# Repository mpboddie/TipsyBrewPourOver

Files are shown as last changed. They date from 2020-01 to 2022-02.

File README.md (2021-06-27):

# TipsyBrew Pour Over Robot (POR for short)
This is an exploratory/educational project that will attempt to tackle a few basic tasks of brewing a damn good cup of coffee.

So the design and approach of this project is to emphasize simplicity and approachability. The basic problems being solved here could be done many ways, but I am going to approach it with these priciples:
1. Use basic consumer items and realtively easy to obtain electrical components. I want to use very common hobbiest level components so that you can easily use what you may have or what you can easily and cheaply obtain where possible. I also want the design to be easily adapted so if you are not able to get the same exact item or you can get a similar one for half the cost then you should do so without major project changes.
2. Make it educational. I am hoping people follow along with this project as it unfolds. I will try to break it down to basic concepts so that you can either learn, skim, or critique.
3. Take what you want from it. I'm not going to have this project completed tomorrow and my decisions may not suit all your needs. But if I move too slow for you and you are capable enough, jump right ahead of my progress. If you are looking to say heat your water with some volcanic geothermal situation going on near you, dump my water heating solution.
4. Cover the basics first. If you make a feature request for a something like a touchscreen or wifi before I can make a solid cup of coffee, expect me to ignore it until later. I believe in simplicity first. However, this is an open project so if you want to add that in a branch, go for it.
5. Communication. I will do my best to convey the reasons behind my decisions as I go. I am sure I will make some mistakes, so please do your best to reciprocate in a constructive manner.

Keep tabs on the everyday progress of this project at [TipsyBrew](https://tipsybrew.com/tags/pourover/). Project code and models will be stored here on GitHub though.

## EarlyPhase (depricated)
This is the exact code that the Phase 0.5 demonstration used. There are some slight issues with this, but nothing that prevents a cup of coffee from being made. I would have preferred to hold it back for some polishing before putting it up here, but I am trying to fight those instincts and make this as public as possible. As always, check [TipsyBrew](https://tipsybrew.com/blog/2020-03-01-success-first-cup-video/) for the 0.5 demonstration and related news on the [pour over project](https://tipsybrew.com/projects). Early Phase was kind of like the moon shot code to demonstrate that the POR would work. It is still being used to make coffee daily to fuel Tipsy during mkII progress, but it is not long for this world.

## Mk II has begun
Mark II of the POR is aimed towards a complete kit for others to build. That means I am trying to create a stable design. At the moment of writing it will be the leading edge design, but once completed I will do my best to heavily document it and hopefully a community will grow with it.

MkII will be TipsyBrew POR's first release.

MkII as of this writing is not complete. However, you are more than welcome to give the code a spin. You will need an ESP32 and an SPI LCD touchscreen using the ILI9341 driver. I believe most of the screens of that type are 320x240 and things will probably work best if you stick with that. The screen I am using at the moment is 2.8 inches, but that has no bearing on get the code running.

Current schematic is below (keep in mind I'm focused on the software at the moment and have already used the missing assorted hardware on MkI):
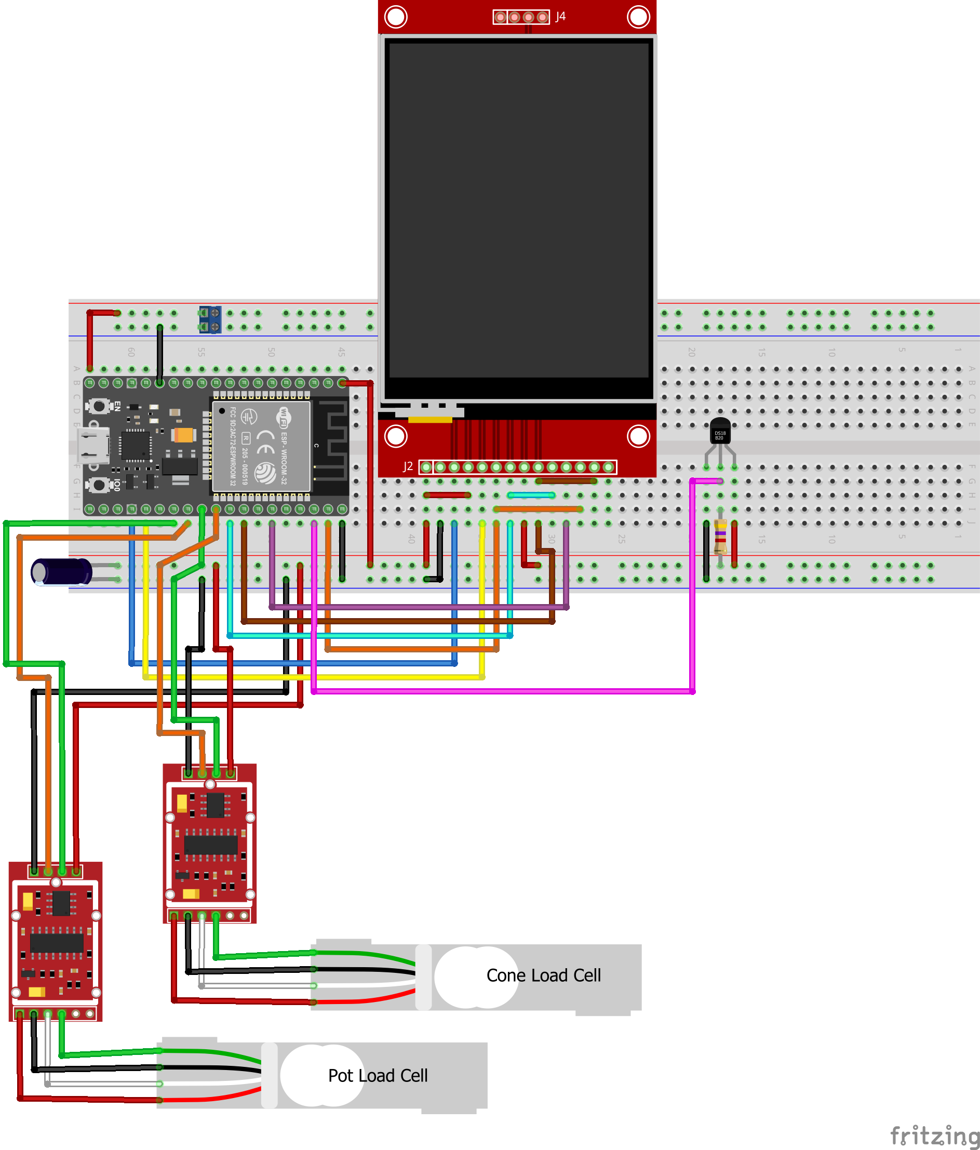
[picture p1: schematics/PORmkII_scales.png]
Schematic

The 10μF capacitor that is bridging GND and 3.3v may not be necessary, but for some ESP32 boards it will prevent the brownout error. The resistor on the DS18B20 is 4.7k Ω.

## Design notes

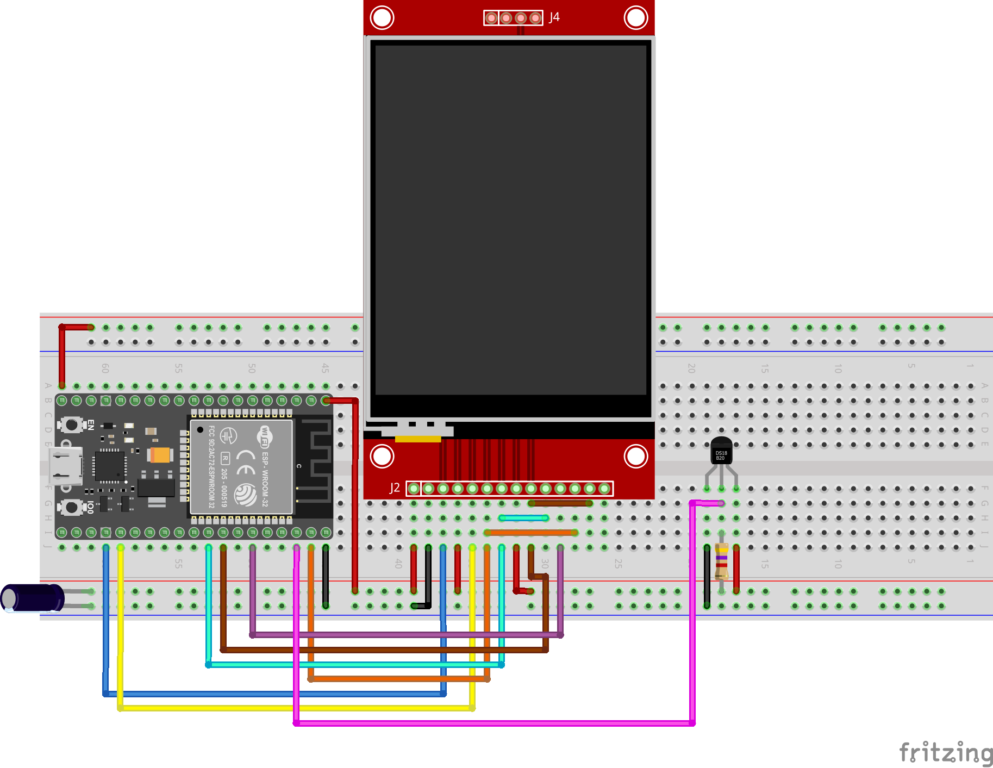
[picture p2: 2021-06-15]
schematics/PORmkII.png

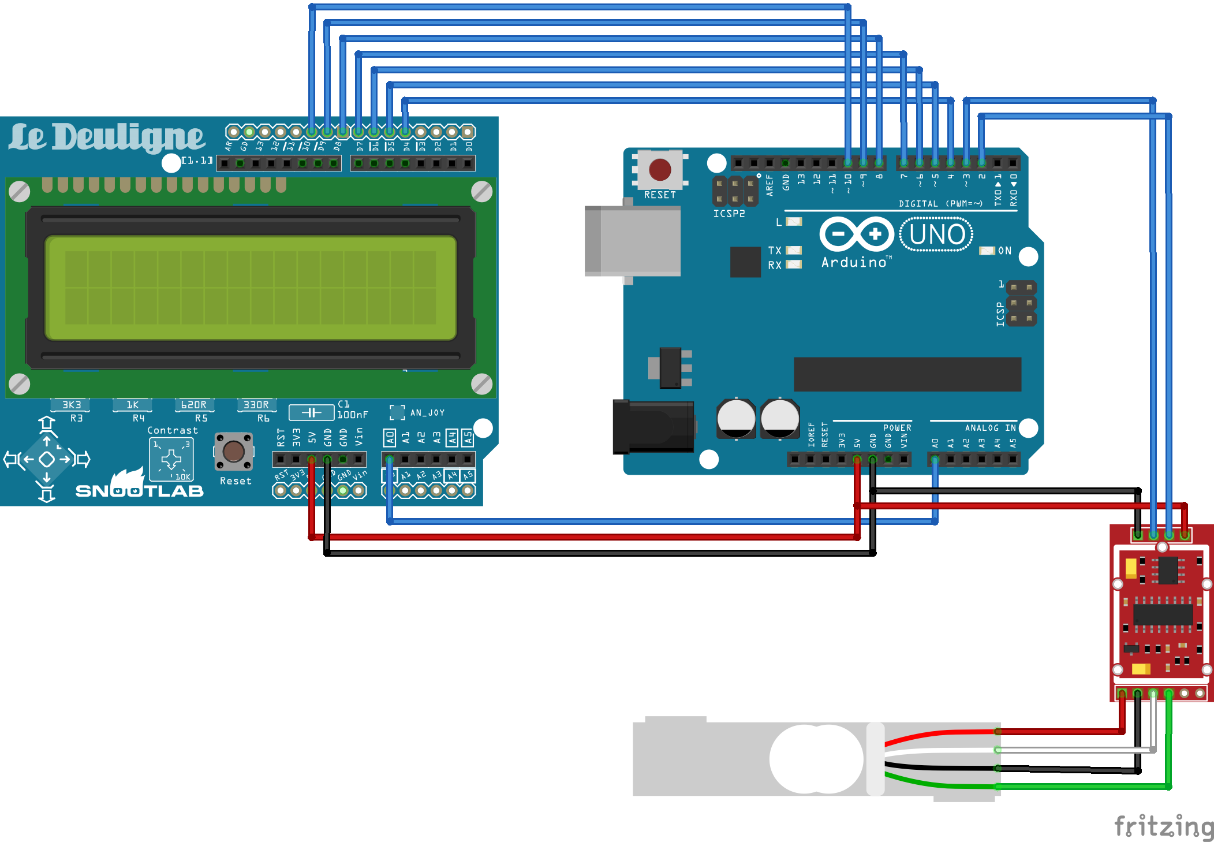
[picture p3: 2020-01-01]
examples/Weight/LoadCell_bb.png

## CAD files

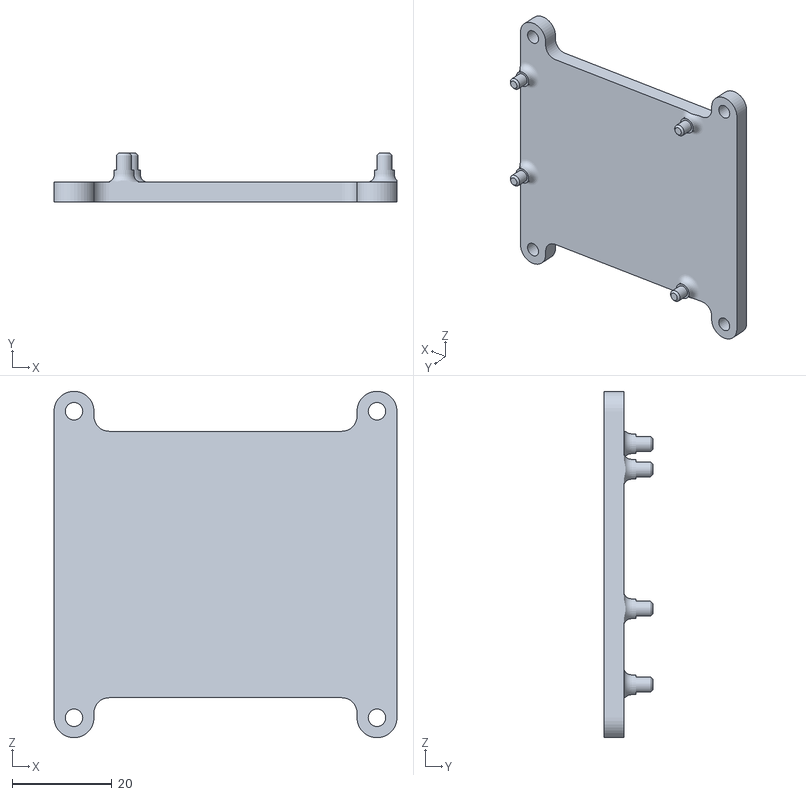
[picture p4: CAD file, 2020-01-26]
3dPrints/ArduinoMount.stl
68.6 x 9.90 x 69.3

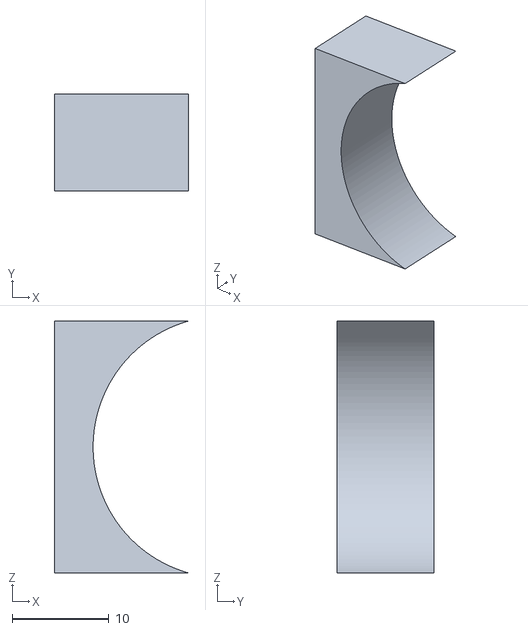
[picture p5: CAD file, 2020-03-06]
3dPrints/DiaphragmPumpMount/DpumpBigBottom.stl
13.9 x 10.0 x 26.0

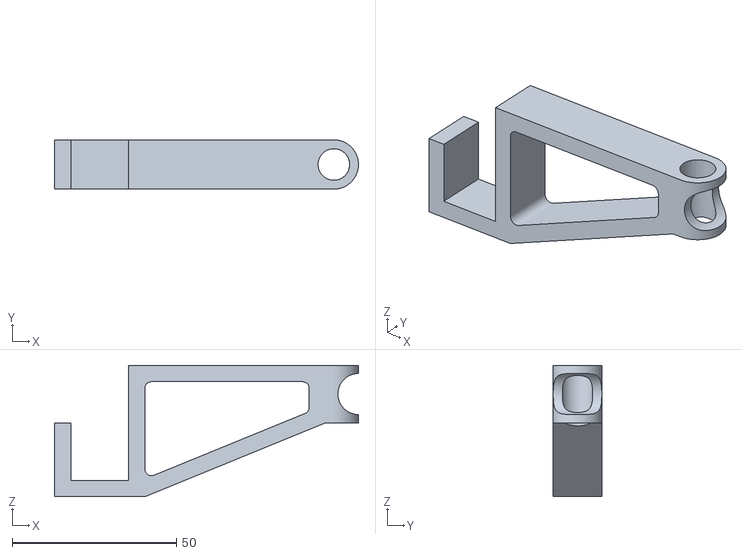
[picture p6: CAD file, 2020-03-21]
3dPrints/Spoon/HoseHolder.stl
92.5 x 15.0 x 40.0

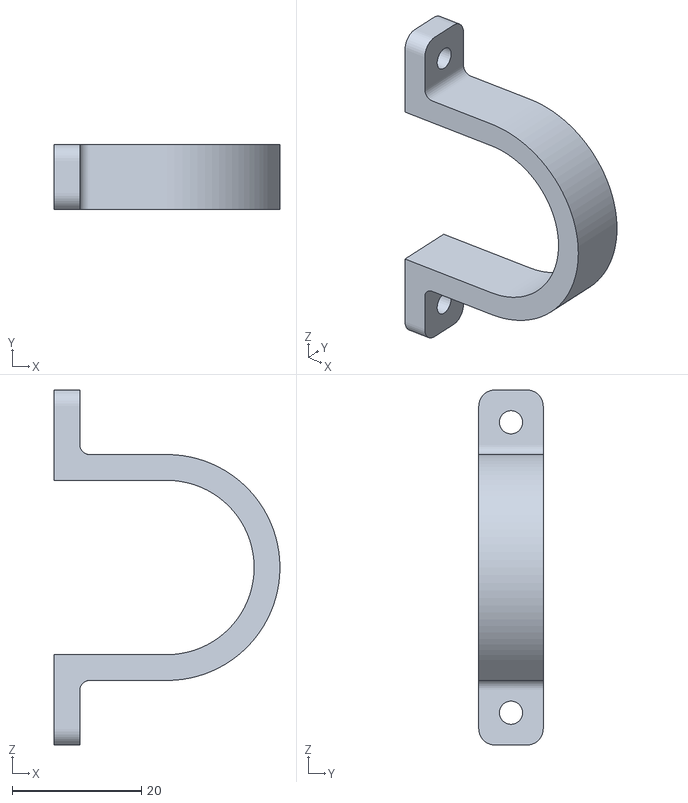
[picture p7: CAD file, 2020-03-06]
3dPrints/DiaphragmPumpMount/DpumpBigTop.stl
35.0 x 10.0 x 55.0

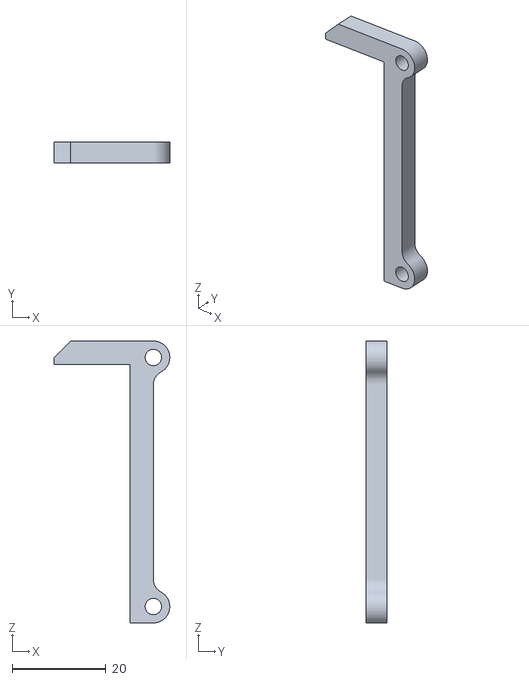
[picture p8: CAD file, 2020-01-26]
3dPrints/digitalPlatformHolder.stl
24.6 x 4.50 x 60.0

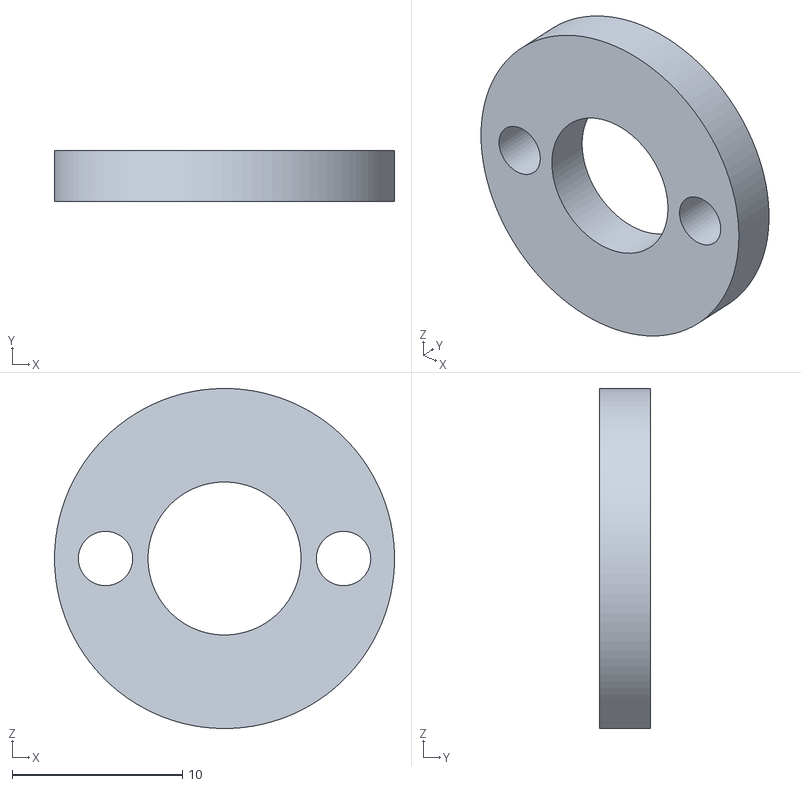
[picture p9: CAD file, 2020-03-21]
3dPrints/Spoon/Spoon2ServoTop.stl
20.0 x 3.00 x 20.0

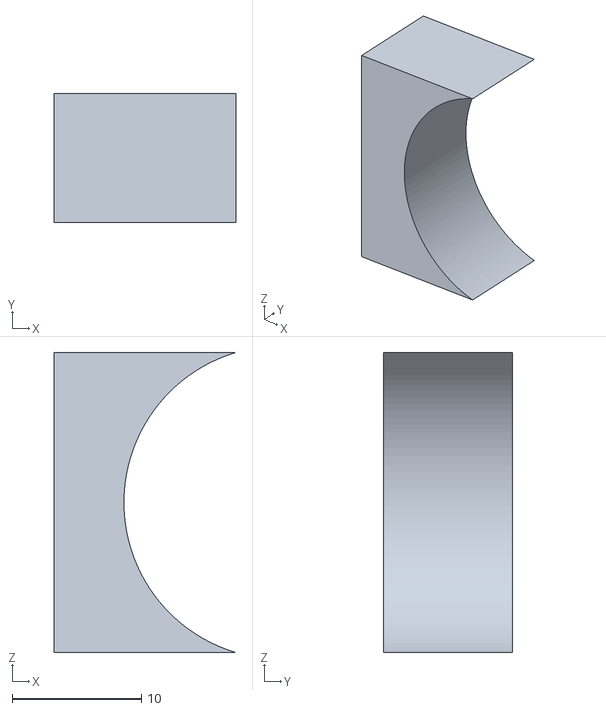
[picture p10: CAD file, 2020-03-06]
3dPrints/DiaphragmPumpMount/DpumpLittleBottom.stl
14.1 x 10.0 x 23.2

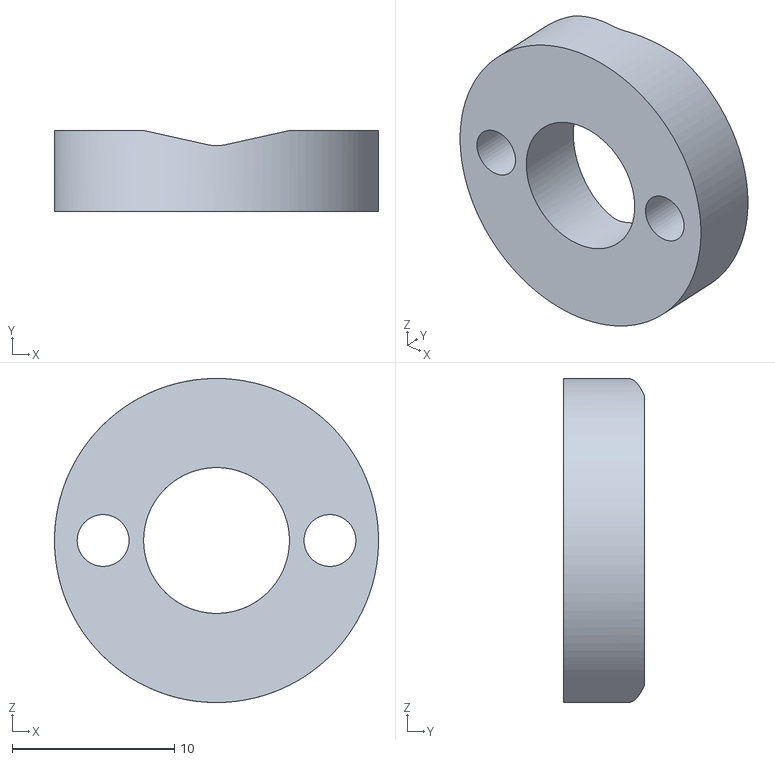
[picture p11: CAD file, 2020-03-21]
3dPrints/Spoon/Spoon2ServoBottom.stl
20.0 x 5.00 x 20.0

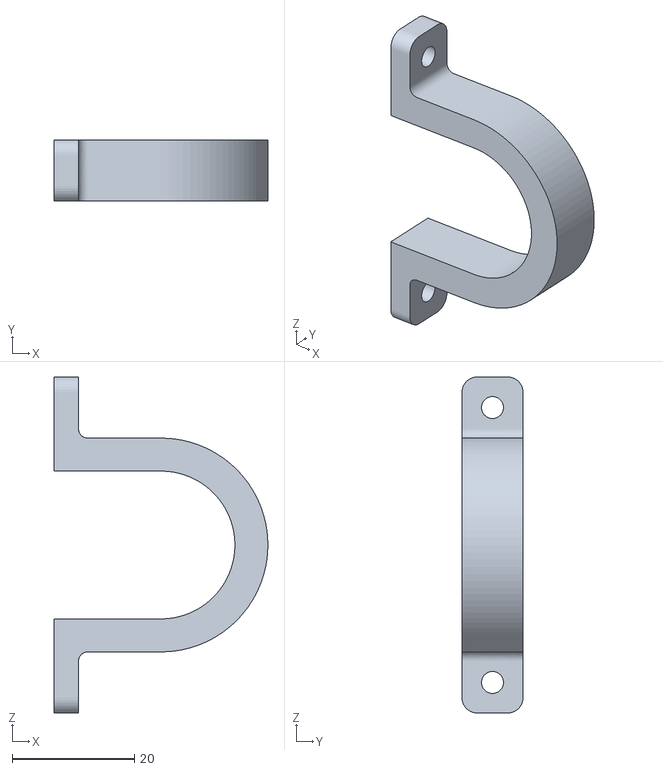
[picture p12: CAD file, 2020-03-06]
3dPrints/DiaphragmPumpMount/DpumpLittleTop.stl
35.0 x 10.0 x 55.0

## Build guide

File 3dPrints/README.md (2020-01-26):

3D Print Files
==============
Here you will find any STL files that were used to make the TipsyBrew pour over machine.

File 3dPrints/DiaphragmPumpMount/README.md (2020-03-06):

### Diaphragm Pump Mount
This mount is pretty basic and not the most elegant but works great. It is for a 12V diaphragm pump that was supplied to me by a generous TipsyBrew Discord user. The pump head is slightly larger than the motor, so there are two separate brackets. Each bracket has a top that goes around the pump and a bottom that gets sandwiched between the pump and the surface you are attaching it to. Although I have not tried it, I suppose you could just use one or two brackets on just the motor or just the head part. The screw holes were made for a #6 screw (sorry metric people, it is what I had laying around).

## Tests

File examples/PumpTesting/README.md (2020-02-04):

Pump Testing
============
**Work in Progress** - Expect some action over here

I have written some code, it is a bit messy and COMPLETELY UNTESTED at the moment.

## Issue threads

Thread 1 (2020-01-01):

Compare HX711 libraries

mpboddie, 2020-01-01:
https://github.com/bogde/HX711 is currently used in the weight example. It may be worthwhile to investigate https://github.com/olkal/HX711_ADC though. It looks like it has a built-in smoothing option. It could be useful.

mpboddie, 2021-06-14:
I've used the bogde library for a while now and I really don't see a need to complicate things. Unless other users see an issue with weight later on, I'm not going to work it.

Closed 2021-06-14.

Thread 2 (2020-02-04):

Evaluate pumps

mpboddie, 2020-02-04:
I've got a commercial diaphragm pump and a self designed peristaltic pump at my disposal at the moment. I need to evaluate what I have to determine the best pump for phase 1. It may also be that the phase 1 pump is not the best pump for the long haul, but lets take it one step at a time.

mpboddie, 2020-03-06:
The diaphragm pump kicked ass for phase 0.5. The peristalitic pump needs some revisions, but I still think it could be a good backup for 3D printing junkies or people who can not obtain a diaphragm pump easily.

mpboddie, 2021-06-14:
The diaphragm pump ended up being not food safe for the parameters used. I have purchased a couple off the shelf peristaltic pumps that seem to be good. They both have the same peristaltic pump head but one is a DC motor and the other a stepper.

A decision has not been made on which one to use yet, so this is still open.

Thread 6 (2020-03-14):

Library organization

mpboddie, 2020-03-14:
Is there a way to link libraries in Arduino? Are we putting enough info in the code about the libraries used?

mpboddie, 2021-06-14:
The move to PlatformIO has fixed this.

Closed 2021-06-14.

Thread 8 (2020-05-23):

Filter rinse does not tare after completion

mpboddie, 2020-05-23:
If the user goes to the filter rinse state, upon completion it goes to the weigh grounds state but it doesn't tare the scale when doing so. The workaround is just having the user manually tare, but it would be better if it was automatically done.

mpboddie, 2021-06-14:
This is an earlyPhase branch issue and we have moved on to MkII. This will not be fixed.

Closed 2021-06-14.

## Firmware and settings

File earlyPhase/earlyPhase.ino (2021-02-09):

// TipsyBrew Pour Over Machine
// by Tipsy
// See http://tipsybrew.com for complete project details
// Version 0.5
// This is a rough start connecting the following components in unison
// - Load cell with HX711 amplifier
// - Diaphragm pump (12v) with L298N driver
// - SSD1306 OLED display (128x64)
// - Keypad 2x3
// Initially this is going to have a limited feature set. You may find it pretty
// rigid and mostly hard coded, however I've had a lot of odd fluke like setbacks
// so I just want to get this thing making a cup of coffee.

#include <SPI.h>
#include <Wire.h>
#include <Adafruit_GFX.h>
#include <Adafruit_SSD1306.h>
#include <Keypad.h>
#include "HX711.h"
#include "ServoEasing.h"
#include "triggy.h"
#include "earlyLibs.h"
#include "screens.h"

// ### App settings ###
// Variables that are required or encouraged to be customized will go here

const byte coffeeRatio = 16;  // Coffee to water ratio (lower number = stronger coffee)
const float waterLoss = 1.995;  // This is used to calculate the amount of water is retained by the coffee grounds

// Calibration factor dependent on your load cell
// You absolutely need to tweak this for your hardware
// See https://tipsybrew.com/blog/2020-01-01-the-hookup-weight-sensor/ for more info
// If you have problems with this let me know so I can make a better calibration guide
#define calibration_factor 1695.0

// Pump speeds
// These define the speed of the pump during bloom and brew, higher = faster
#define BLOOM_SPEED 100
#define BREW_SPEED 90
#define BLOOM_WAIT 30000
#define DRAWDOWN_TIME 20000

// Pour arm settings
// These values should be changed to fit your brewer. If you have a limited space there is nothing preventing the servo from turning into your stand, so maybe test gently.

// left to right is referred to as the X
//const int leftAngle = 88;   // servo setting to set arm to the human's far left perspective
//const int rightAngle = 124; // servo setting to set arm to the human's far right perspective
#define MID_ANGLE 94  // This should be 90 on a 180 degree servo... but sometimes shit happens and the worlds don't align

// front to back is referred to as the Y
const int frontDistance = 5; // servo setting to set arm to the human's far front perspective
const int backDistance = 180; // servo setting to set arm to the human's far back perspective

// number of ms between steps of arm move
// NOTE: this is kind of done in a dumb way, but it is an example of GEFN (good enough for now)
#define ARM_SPEED 100

// Do change the pourCoord arrays if you want
#define NUM_BLOOM_SPOTS 10
pourCoord bloomSpots[NUM_BLOOM_SPOTS];

// BREW_RADIUS and BREW_DISTANCE are in servo steps as units
// Radius defines the max radius of the brew circle
// Distance is the servo arm distance to the center of the brewer, assuming the arm is also angle center
#define BREW_RADIUS 60
#define BREW_DISTANCE 102.5
#define BREW_RESOLUTION 20  // must divide 360 evenly
pourCoord brewSpots[BREW_RESOLUTION];

// Kettle values
#define KETTLE_ON 74
#define KETTLE_NEUTRAL 50
#define KETTLE_OFF 32

// Turns on a servo test during the startup screen
const bool servoTest = false;
// debug flag
const bool debug = false;

// Cone limit
// I STRONGLY SUGGEST you start small and work your way up if you so choose on cone limit.
// This limits the number of ml dispensed during a brew cycle before pausing for a drawdown.
// Let me say it another way, if you increase this too much HOT WATER WILL OVERFLOW making a huge mess in the best case scenario.
const int coneLimit = 225;

// ### Functions and variable initialization ###

enum AppModeValues
{
  APP_INTRO_SCREEN,
  APP_NORMAL_MODE,
  APP_SERVO_TEST,
  APP_FILTER_RINSE,
  APP_CONFIRM_START,
  APP_BLOOM,
  APP_BREW,
  APP_BREW_COMPLETE
};

byte appMode = APP_INTRO_SCREEN;

void runPump();
void stopPump();
void pumpSpeed(byte dcSpeed);

// Timing variables
unsigned long startMillis;
unsigned long currentMillis;

// Weight variables
float weightRead = 0;
float prevWeight = 0;
float groundWeight = 0;

// Bloom time
unsigned long bloomTimer;

// Brew variables
int brewPosition = 0;
int currentAngle;
int currentDistance;

void setup() {
  Serial.begin(9600);

  // initialize with the I2C addr 0x3C
  if(!display.begin(SSD1306_SWITCHCAPVCC, 0x3C)) {
    Serial.println(F("SSD1306 allocation failed"));
    for(;;); // Don't proceed, loop forever
  }

  // Set all the motor control pins to outputs
  pinMode(enA, OUTPUT);
  pinMode(in1, OUTPUT);
  pinMode(in2, OUTPUT);

  // Turn off motors - Initial state
  stopPump();
  
  // Title screen... completely unecessary
  display.clearDisplay();
  // Display bitmap
  display.drawBitmap(0, 0, TipsyBrew, 128, 64, WHITE);
  display.display();
  startMillis = millis();
  while( millis() - startMillis < 5000 ) {
    if ( keypad.getKey() ) break;
  }

  // populate brew path
  float angleIncrement = 360/BREW_RESOLUTION;
  for (int i=0; i<BREW_RESOLUTION; i++) {
    Serial.print(i);
    double distance = SASdistance(BREW_DISTANCE, BREW_RADIUS, i*angleIncrement);
    double angle = SSAngle(BREW_RADIUS, i*angleIncrement, distance) + MID_ANGLE;
    //distance = reverseDistance(distance);
    brewSpots[i] = {(int)angle, (int)distance};
    
    Serial.print(F(" - ("));
    Serial.print(angle, 1);
    Serial.print(F(", "));
    Serial.print(distance, 1);
    Serial.println(F(")"));
    if (debug) {
      display.clearDisplay();
      display.setTextSize(1);
      display.setTextColor(WHITE);
      display.setCursor(0,10);
      display.println(i);
      display.print(angle, 1);
      display.print(F(", "));  
      display.println(distance, 1);
      display.display();
      delay(500);
    }
  }

  int bloomRadius = 30;
  angleIncrement = 360/NUM_BLOOM_SPOTS;
  for (int i=0; i<NUM_BLOOM_SPOTS; i++) {
    double distance = SASdistance(BREW_DISTANCE, bloomRadius, i*angleIncrement);
    double angle = SSAngle(bloomRadius, i*angleIncrement, distance) + MID_ANGLE;
    distance = reverseDistance(distance);
    bloomSpots[i] = {(int)angle, (int)distance};
  }
  
  if ( servoTest ) {
    Serial.println(F("Servo Test"));
    // servo test cycle
    angleIncrement = 360/BREW_RESOLUTION;
    angleServo.attach(anglePin, 1300, 1700);
    distanceServo.attach(distancePin);
    angleServo.setSpeed(10);
    distanceServo.setSpeed(70);
    distanceServo.write(93);
    angleServo.write(93);
    delay(3000);
    for (int i=0; i < BREW_RESOLUTION; i++) {
      Serial.print(i*angleIncrement);
      Serial.print(F(" - ("));
      Serial.print(brewSpots[i].angle, 1);
      Serial.print(F(", "));
      Serial.print(brewSpots[i].distance, 1);
      Serial.println(F(")"));
      distanceServo.startEaseTo(brewSpots[i].distance);
      angleServo.startEaseTo(brewSpots[i].angle);
      synchronizeAllServosAndStartInterrupt();
      while(distanceServo.isMoving() || angleServo.isMoving()) {
        if ( distanceServo.isMoving() ) {
          Serial.print(F("Distance "));
        }
        if ( angleServo.isMoving() ) {
          Serial.print(F("Angle"));
        }
        Serial.println(F(" "));
      }
    }
    distanceServo.startEaseTo(brewSpots[0].distance);
    angleServo.startEaseTo(brewSpots[0].angle);
    synchronizeAllServosAndStartInterrupt();
    while(distanceServo.isMoving() || angleServo.isMoving()) {
      if ( distanceServo.isMoving() ) {
        Serial.print(F("Distance "));
      }
      if ( angleServo.isMoving() ) {
        Serial.print(F("Angle"));
      }
      Serial.println(F(" "));
    }
    angleServo.detach();
    distanceServo.detach();
    Serial.print(F("Done with Servo Test"));
  }

  startKettle();
  
  // Make sure the pour spout is out of the way for convenient dead bean loading
  angleServo.attach(anglePin, 1000, 2000);
  distanceServo.attach(distancePin);
  angleServo.write(MID_ANGLE);
  distanceServo.write(frontDistance);
  delay(500);
  distanceServo.detach();
  angleServo.detach();
  
  // Intro
  display.clearDisplay();
  display.setTextSize(1);
  display.setTextColor(WHITE);
  display.setCursor(0,10);
  display.println(F("Place a prepared"));
  display.println(F("brewer in the machine"));  
  display.println(F("WITHOUT any grounds"));
  display.display();
  delay(1000);
  display.setCursor(10,44);
  display.println(F("Press any key to"));
  display.println(F("continue."));
  display.display();

  scale.begin(LOADCELL_DOUT_PIN, LOADCELL_SCK_PIN);
  scale.set_scale(calibration_factor);
  //Assuming there is no weight on the scale at start up, reset the scale to 0
  scale.tare();
}

void loop() {
  
  char key = keypad.getKey(); // Read the key

  switch (appMode)
  {
    case APP_INTRO_SCREEN :
      if (key) {
        if (key == 'U') {
          display.clearDisplay();
          appMode = APP_FILTER_RINSE;
        } else if (key == 'L') {
          display.clearDisplay();
          currentAngle = 90;
          currentDistance = 90;
          angleServo.attach(anglePin, 1000, 2000);
          distanceServo.attach(distancePin);
          angleServo.write(currentAngle);
          distanceServo.write(currentDistance);
          delay(100);
          angleServo.detach();
          distanceServo.detach();
          appMode = APP_SERVO_TEST;
        } else {
          scale.tare();
          display.clearDisplay();
          appMode = APP_NORMAL_MODE;
          weightRead = -100; // this forces a refresh
        }
      }
      break;
    case APP_SERVO_TEST :
      displayServoTest(currentAngle, currentDistance);
      if (key == 'U') {
        if (currentDistance < 180) {
          currentDistance++;
          distanceServo.attach(distancePin);
          distanceServo.write(currentDistance);
          delay(100);
          distanceServo.detach();
        }
      } else if (key == 'D') {
        if (currentDistance > 0) {
          currentDistance--;
          distanceServo.attach(distancePin);
          distanceServo.write(currentDistance);
          delay(100);
          distanceServo.detach();
        }
      } else if (key == 'L') {
        if (currentAngle > 0) {
          currentAngle--;
          angleServo.attach(anglePin, 1000, 2000);
          angleServo.write(currentAngle);
          delay(100);
          angleServo.detach();
        }
      } else if (key == 'R') {
        if (currentAngle < 180) {
          currentAngle++;
          angleServo.attach(anglePin, 1000, 2000);
          angleServo.write(currentAngle);
          delay(100);
          angleServo.detach();
        }
      } else if (key) {
        display.clearDisplay();
        appMode = APP_INTRO_SCREEN;
        displayIntro();
      }
      break;
    case APP_FILTER_RINSE :
      displayFilterRinse();
      if (key == 'L') {
        display.clearDisplay();
        appMode = APP_NORMAL_MODE;
      } else if (key == 'D') {
        display.clearDisplay();
        display.setTextSize(2);
        display.setTextColor(WHITE);
        display.setCursor(0,10);
        display.println(F("  Rinsing"));
        display.println(F("    In"));
        display.println(F(" Progress"));
        display.display();
        int filterResolution = 36;
        pourCoord filterRinse[filterResolution];
        drawCircle(50, filterResolution, BREW_DISTANCE, MID_ANGLE, filterRinse);
        angleServo.attach(anglePin, 1000, 2000);
        distanceServo.attach(distancePin);
        pumpSpeed(BREW_SPEED);
        runPump();
        for(int i = 0; i < filterResolution; i++) {
          angleServo.write(filterRinse[i].angle);
          distanceServo.write(filterRinse[i].distance);
          delay(200);
        }
        angleServo.write(filterRinse[0].angle);
        distanceServo.write(filterRinse[0].distance);
        delay(100);
        stopPump();
        angleServo.detach();
        distanceServo.detach();
      }
      break;
    case APP_NORMAL_MODE :
      // Display active weight, calculate what the weight means for finished coffee
      prevWeight = weightRead;
      weightRead = scale.get_units();
      if ( weightRead < 1 ) {
        display.clearDisplay();
        display.setTextSize(2);
        display.setTextColor(WHITE);
        display.setCursor(0,20);
        display.println(F(" FEED ME"));
        display.println(F("DEAD BEANS"));
        display.display();
      } else if ( weightRead < 5 ) {
        display.clearDisplay();
        display.setTextSize(2);
        display.setTextColor(WHITE);
        display.setCursor(0,10);
        display.println(F("MORE BEANS"));
        display.println(F(" STOOPID"));
        display.println(F("HOOMAN!!!"));
        display.display();
      } else if ( abs(weightRead - prevWeight) > 0.1 ) { // refresh display
        display.clearDisplay();
        display.setTextSize(1);
        display.setTextColor(WHITE);
        display.setCursor(0,10);
        display.print(F("Dead beans: "));
        display.print(weightRead, 1);
        display.println(F(" g"));
        display.print(F("Water used: "));
        display.print((weightRead*coffeeRatio), 1);
        display.println(F(" ml"));
        display.print(F("Coffee made:"));
        display.print(((weightRead*coffeeRatio) - (weightRead*waterLoss)), 1);
        display.println(F(" ml")); 
        display.println(F(" "));
        display.println(F("Press UP to tare"));
        display.println(F("COFFEE NOW to Brew"));
        display.display();  
      }
      if ( key == 'U' ) {
        // Tare the scale with the A button
        scale.tare();
      } else if ( key == 'C' ) {
        // Start the brew with the * button
        appMode = APP_CONFIRM_START;
        display.clearDisplay();
        display.setTextSize(1);
        display.setTextColor(WHITE);
        display.setCursor(0,0);
        display.println(F("You are about to make"));
        display.print(((weightRead*coffeeRatio) - (weightRead*waterLoss)), 1);
        display.println(F(" ml of coffee"));
        display.println(F(" "));
        display.println(F("Are you sure?"));
        display.println(F(" "));
        display.println(F("SELECT to Continue"));
        display.println(F("ANY KEY to Cancel"));
        display.display();
      }
      break;
    case APP_CONFIRM_START :
      // Confirm start with the 1 button
      if ( key == 'S' ) {
        groundWeight = weightRead;
        appMode = APP_BLOOM;
        display.clearDisplay();
      } else if ( key ) {
        appMode = APP_NORMAL_MODE;
        display.clearDisplay();
        weightRead = -100; // forces a refresh
      }
      break;
    case APP_BLOOM :
      // Dispense total water*bloom and wait
      display.setTextSize(1);
      display.setTextColor(WHITE);
      display.setCursor(0,0);
      display.println(F("Bloom in Progress!"));
      display.println(F("Do not touch brewer"));
      display.display();
      scale.tare(); // weight from this point on is water dispensed only

      // To start the bloom put the spout dead center
      angleServo.attach(anglePin, 1000, 2000);
      distanceServo.attach(distancePin);
      angleServo.write(MID_ANGLE);
      distanceServo.write(BREW_DISTANCE);
      delay(500);
      distanceServo.detach();
      angleServo.detach();
      
      pumpSpeed(BLOOM_SPEED);
      runPump();
      bloomTimer = millis();
      while (scale.get_units() < groundWeight) {
        // possibly display weight to the user, but do they really care?
        // just do nothing for now
      }
      bloomTimer = millis() - bloomTimer; // tells us how long the first half of the bloom took
      stopPump();

      brewPosition = 0;
      bloomTimer = 0;
      angleServo.attach(anglePin, 1000, 2000);
      distanceServo.attach(distancePin);
      runPump();
      while (scale.get_units() < (2*groundWeight)) {
        if ( millis() >= bloomTimer + ARM_SPEED ) {
          bloomTimer = millis();
          angleServo.write(bloomSpots[brewPosition % NUM_BLOOM_SPOTS].angle);
          distanceServo.write(bloomSpots[brewPosition % NUM_BLOOM_SPOTS].distance);
          brewPosition += 1;
        }
      }
      stopPump();
      distanceServo.detach();
      angleServo.detach();
      
      display.clearDisplay();
      display.setTextSize(1);
      display.setTextColor(WHITE);
      display.setCursor(0,20);
      display.println(F("     BLOOMING"));
      display.println(F("Do not touch brewer"));
      display.print(scale.get_units(), 1);
      display.println(F(" g dispensed"));
      display.display();
      delay(BLOOM_WAIT);

      // Adjust spout to center
      angleServo.attach(anglePin, 1000, 2000);
      distanceServo.attach(distancePin);
      currentAngle = (int) MID_ANGLE;
      currentDistance = (int) BREW_DISTANCE;
      angleServo.write(currentAngle);
      distanceServo.write(currentDistance);
      delay(100);
      distanceServo.detach();
      angleServo.detach();
      
      // Move on to the brewing step
      appMode = APP_BREW;
      break;
    case APP_BREW :
      pumpSpeed(BREW_SPEED);
      bool complete = false;
      float waterRound = scale.get_units();   // This acts as a sort of tare without losing live total weight, subtract it from the current weight to get the weight of the current pour
      
      // For loop dispense <coneLimit> ml of water or amount remaining then wait
      while (scale.get_units() < (coffeeRatio * groundWeight)) { // stay in loop until we have pumped the needed water
        float waterLeft = (coffeeRatio * groundWeight) - scale.get_units();   // live count of water still required
        if ( waterLeft > coneLimit ) {
          waterLeft = coneLimit;    // if the amount of water required is over the amount of water you want in the cone at one moment just pour the max amount
        } else {
          complete = true;          // else pour what is left and call it
        }
        
        startMillis = millis();
        brewPosition = 0;
        unsigned long lastMove = startMillis;
        
        angleServo.attach(anglePin, 1000, 2000);
        distanceServo.attach(distancePin);
        
        while ( waterLeft > (scale.get_units() - waterRound) ) {
          startMillis = millis();
          display.clearDisplay();
          display.setTextSize(1);
          display.setTextColor(WHITE);
          display.setCursor(0,0);
          display.println(F("Brewing Cycle!!!"));
          display.println(F("Do not touch the brewer"));
          display.print(scale.get_units(), 1);
          display.print(F(" of "));
          display.print(coffeeRatio * groundWeight, 1);
          display.println(F("g"));
          
          if ( complete ) {
            display.println(F("Last Round!"));
          }
          display.display();
          runPump();
          
          if (lastMove + ARM_SPEED <= startMillis) {
            angleServo.write(brewSpots[brewPosition % BREW_RESOLUTION].angle);
            distanceServo.write(brewSpots[brewPosition % BREW_RESOLUTION].distance);
            lastMove = startMillis;
            brewPosition++;
          }
        }
        stopPump();
        
        if ( complete ) {
          appMode = APP_BREW_COMPLETE;
          angleServo.detach();
          distanceServo.detach();
        } else {
          display.clearDisplay();
          display.setTextSize(1);
          display.setTextColor(WHITE);
          display.setCursor(0,0);
          display.println(F("Drawdown Cycle!!!"));
          display.println(F("Do not touch brewer"));
          display.print(scale.get_units(), 1);
          display.println(" g dispensed");
          display.display();
          currentAngle = (int) MID_ANGLE;
          currentDistance = (int) BREW_DISTANCE;
          angleServo.write(currentAngle);
          distanceServo.write(currentDistance);
          delay(1000);
          angleServo.detach();
          distanceServo.detach();
          delay(DRAWDOWN_TIME - 1000);
          waterRound = scale.get_units();
        }
      }
      appMode = APP_BREW_COMPLETE;
      break;
    case APP_BREW_COMPLETE :
      // Display that brew is done and wait for input
      display.clearDisplay();
      display.setTextSize(1);
      display.setTextColor(WHITE);
      display.setCursor(0,0);
      display.println(F("Brewing is complete"));
      display.println(F("Allow time for drawdown"));
      display.println(F("if still neccessary"));
      display.println(F(" "));
      display.println(F("Press any key to"));
      display.println(F("continue"));
      display.display();
      if ( key ) {
        appMode = APP_NORMAL_MODE;
        display.clearDisplay();
      }
      break;
  }
}

void runPump() {
  digitalWrite(in1, HIGH);
  digitalWrite(in2, LOW);
}

void stopPump() {
  digitalWrite(in1, LOW);
  digitalWrite(in2, LOW);
}

void pumpSpeed(byte dcSpeed) {
  analogWrite(enA, dcSpeed);
}

void startKettle() {
  kettleServo.attach(kettlePin);
  kettleServo.write(KETTLE_ON);
  delay(1000);
  kettleServo.write(KETTLE_NEUTRAL);
  delay(1000);
  kettleServo.detach();
}

void stopKettle() {
  kettleServo.attach(kettlePin);
  kettleServo.write(KETTLE_OFF);
  delay(1000);
  kettleServo.write(KETTLE_NEUTRAL);
  delay(1000);
  kettleServo.detach();
}

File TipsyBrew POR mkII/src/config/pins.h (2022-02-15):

#ifndef PINS
#define PINS

// One-wire bus (used by temp sensor)
#define ONE_WIRE                    22

// Weight sensors
#define CONE_LOADCELL_DOUT_PIN  5       // Cone HX711 DOUT pin
#define CONE_LOADCELL_SCK_PIN   17      // Cone HX711 SCK pin

#define POT_LOADCELL_DOUT_PIN   16      // Pot HX711 DOUT pin
#define POT_LOADCELL_SCK_PIN    4       // Pot HX711 SCK pin

// Steppers
#define PUMP_DIR_PIN            34
#define PUMP_STEP_PIN           35
#define PUMP_STEPS_REV          200
#define PUMP_INTERFACE_TYPE     1

#endif

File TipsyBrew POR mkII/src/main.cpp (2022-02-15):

#include <Arduino.h>

#include <WiFi.h>
#include <time.h>
//#include <WiFiClient.h>
//#include <WebServer.h>
//#include <ESPmDNS.h>
#include <SPIFFS.h>
//#include <FS.h>
#include <SPI.h>
#include <TFT_eSPI.h> // Graphics and font library for ILI9341 driver chip
#include <OneWire.h>
#include <DallasTemperature.h>
#include <HX711.h>
#include <AccelStepper.h>

#include "config/pins.h"
#include "config/userSettings.h"
#include "config/settingsSPIFFS.h"
#include "states.h"

#include "tasks/wifiConnection.h"
#include "tasks/weights.h"
#include "tasks/display.h"
#include "tasks/ntpTime.h"
#include "tasks/kettleTemp.h"
#include "tasks/motors.h"

// Which core is Arduino running on
#if CONFIG_FREERTOS_UNICORE
#define ARDUINO_RUNNING_CORE 0
#else
#define ARDUINO_RUNNING_CORE 1
#endif

#define BLACK 0x0000
#define WHITE 0xFFFF
#define GREY  0x5AEB

AppValues appState;
TFT_eSPI tft = TFT_eSPI();

OneWire oneWire(ONE_WIRE);
DallasTemperature sensors(&oneWire);

AccelStepper pumpMotor(PUMP_INTERFACE_TYPE, PUMP_STEP_PIN, PUMP_DIR_PIN);

// This is the file name used to store the calibration data
// You can change this to create new calibration files.
// The SPIFFS file name must start with "/".
#define CALIBRATION_FILE "/TouchCalData1"

// Set REPEAT_CAL to true instead of false to run calibration
// again, otherwise it will only be done once.
// Repeat calibration if you change the screen rotation.
#define REPEAT_CAL false

void touch_calibrate();

void setup(void) {
  pinMode(0, OUTPUT);
  digitalWrite(0, HIGH);

  appState.currentScreen = APP_INTRO_SCREEN;
  appState.kettleTemp = 0;
  appState.kettleChange = true;
  appState.kettleState = false;
  appState.ipAddress = "0.0.0.0";
  appState.wifiState = WIFI_DISCONNECTED;
  appState.debugMessage = "Starting";
  appState.screenRefresh = false;
  appState.preheatStatus = false;
  appState.activityTimer = millis();
  appState.coneWeight = 0.0;
  appState.potWeight = 0.0;
  appState.tareMsg = TARE_ALL;
  appState.pumpSpeed = 200;
  appState.pumpAccel = 50;
  appState.pumpState = false;

  // Setup the LCD
  tft.begin();
  tft.setRotation(1);
  tft.fillScreen(BKGD);
  tft.setTextColor(TFT_WHITE, BKGD);

  // Calibrate the touch screen and retrieve the scaling factors
  touch_calibrate();

  Serial.begin(115200);
  Serial.println(F("[MAIN]TipsyBrew started"));

  initScales();

  configTime(gmtOffset_sec, daylightOffset_sec, ntpServer);

  if(!loadCoffeeSettings(filename, coffeeSettings)) {
    saveCoffeeSettings(filename, coffeeSettings);
  }
  // Uncomment next two lines for debugging settings file issues
  //Serial.print(F("[MAIN]Settings file dump: "));
  //printFile(filename);

  pumpMotor.setMaxSpeed(1000);
	pumpMotor.setAcceleration(appState.pumpAccel);
	pumpMotor.setSpeed(appState.pumpSpeed);
	pumpMotor.moveTo(200);

  xTaskCreatePinnedToCore(
    keepWiFiAlive,
    "keepWiFiAlive",  // Task name
    5000,             // Stack size (bytes)
    NULL,             // Parameter
    1,                // Task priority
    NULL,             // Task handle
    ARDUINO_RUNNING_CORE
  );
  
  xTaskCreate(
    updateDisplay,
    "UpdateDisplay",  // Task name
    15000,             // Stack size (bytes)
    NULL,             // Parameter
    2,                // Task priority
    NULL              // Task handle
  );
  
  xTaskCreate(
    updateDateTime,
    "UpdateDateTime", // Task name
    5000,             // Stack size (bytes)
    NULL,             // Parameter
    4,                // Task priority
    NULL              // Task handle
  );

  xTaskCreate(
    updateKettleTemp,
    "UpdateKettleTemp", // Task name
    5000,             // Stack size (bytes)
    NULL,             // Parameter
    3,                // Task priority
    NULL              // Task handle
  );

  xTaskCreate(
    updateWeights,
    "UpdateWeights",  // Task name
    5000,             // Stack size (bytes)
    NULL,             // Parameter
    3,                // Task priority
    NULL              // Task handle
  );

  xTaskCreate(
    updateMotors,
    "UpdateMotors",   // Task name
    5000,             // Stack size (bytes)
    NULL,             // Parameter
    3,                // Task priority
    NULL              // Task handle
  );

}

void loop(void) {
  //vTaskDelay(10000 / portTICK_PERIOD_MS);
}

void touch_calibrate()
{
  uint16_t calData[5];
  uint8_t calDataOK = 0;

  // check file system exists
  if (!SPIFFS.begin()) {
    Serial.println("Formating file system");
    SPIFFS.format();
    SPIFFS.begin();
  }

  // check if calibration file exists and size is correct
  if (SPIFFS.exists(CALIBRATION_FILE)) {
    if (REPEAT_CAL)
    {
      // Delete if we want to re-calibrate
      SPIFFS.remove(CALIBRATION_FILE);
    }
    else
    {
      File f = SPIFFS.open(CALIBRATION_FILE, "r");
      if (f) {
        if (f.readBytes((char *)calData, 14) == 14)
          calDataOK = 1;
        f.close();
      }
    }
  }

  if (calDataOK && !REPEAT_CAL) {
    // calibration data valid
    tft.setTouch(calData);
  } else {
    // data not valid so recalibrate
    tft.fillScreen(TFT_BLACK);
    tft.setCursor(20, 0);
    tft.setTextFont(2);
    tft.setTextSize(1);
    tft.setTextColor(TFT_WHITE, TFT_BLACK);

    tft.println("Touch corners as indicated");

    tft.setTextFont(1);
    tft.println();

    if (REPEAT_CAL) {
      tft.setTextColor(TFT_RED, TFT_BLACK);
      tft.println("Set REPEAT_CAL to false to stop this running again!");
    }

    tft.calibrateTouch(calData, TFT_MAGENTA, TFT_BLACK, 15);

    tft.setTextColor(TFT_GREEN, TFT_BLACK);
    tft.println("Calibration complete!");

    // store data
    File f = SPIFFS.open(CALIBRATION_FILE, "w");
    if (f) {
      f.write((const unsigned char *)calData, 14);
      f.close();
    }
  }
}

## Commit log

2020-01-27 Delete Arduino Mount.stl
    I just didn't like the space in the name
    [Arduino Mount.stl]
2020-03-06 Added diaphragm pump mount 3d models
    [DpumpBigBottom.stl, DpumpBigTop.stl, DpumpLittleBottom.stl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]
2020-03-11 Fixes for intro screen and scale
    There was a delay with the intro screen of unknown origin. Turns out it was some primitive weight refreshing I only half implemented causing the screen to only appear once the weight changed. I finished the weight check and that fixed the screen delay. The weight display is improved as a happy coincidence.
    [earlyPhase.ino]
2020-03-21 earlyPhase updates and additions
    earlyPhase now uses a 2x3 button configuration. A servo controlled spoon
    defuser is now used as well. The new hose holder and spoon to servo
    bracket is added to the 3D models.
    [HoseHolder.stl, Spoon2ServoBottom.stl, Spoon2ServoTop.stl]
2020-03-21 Missed earlyPhase in the last commit
    [earlyPhase.ino]
2021-02-10 Added a sample user settings file to be duplicated by the user
2021-02-14 Changed a bit of the button drawing to add the ability to use big buttons as a toggle. See the Pre-heat button as an example. Other minor UI additions as well.
2021-02-15 Added a temp probe.
2021-05-24 added bmp and sample settings
2021-05-27 Added some button draw functions and tested out the touchscreen
2021-05-28 Preheat button toggles, other buttons are recognized but don't do much yet
2021-06-13 Added some missing items in settings sample cleaned some other stuff up
    [userSettings.sample.h]
2021-06-15 Current schematic is drawn up, minor pin change
    [PORmkII.fzz]
2021-06-15 Update README.md
    Added schematic to README
2021-06-21 minor power additions
    [PORmkII.fzz]
2021-06-26 Added Scales to the Schematic
    [PORmkII.fzz]
2021-06-26 Update README.md
    Added scales to schematic
2021-06-27 Slightly moved cone scale to reduce overlap
    [PORmkII.fzz]
2021-11-28 Disabling the Pre-Heat was not turning off the kettle
2022-01-24 Lack of settings file or scales no longer blocking
    [main.cpp]
2022-02-13 Added stepper pins Also, debug adjustments and vscode changes due to update
2022-02-15 Started adding stepper motor code
2022-02-18 The new motor task was causing havoc because I left the for loop out
